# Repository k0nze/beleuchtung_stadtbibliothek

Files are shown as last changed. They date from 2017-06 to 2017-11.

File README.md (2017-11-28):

# Beleuchtung der LEGO Stadtbibliothek Stuttgart

## Platine
KiCad Projekt:
[beleuchtung_stadtbibliothek.pro](./kicad/beleuchtung_stadtbibliothek.pro)

Pin-Belegung `CON1`:

 * 1 => `VCC`
 * 2 => `GND`
 * 3 => `CLK`
 * 4 => Clear für für Schieberegister
 * 5 => Data-Input für Schieberegister 
 * 6 => Enable für LED-Treiber 

### Schaltplan
[beleuchtung_stadtbibliothek.sch](./kicad/beleuchtung_stadtbibliothek.sch)

### Layout/PCB
[beleuchtung_stadtbibliothek.kicad_pcb](./kicad/beleuchtung_stadtbibliothek.kicad_pcb)

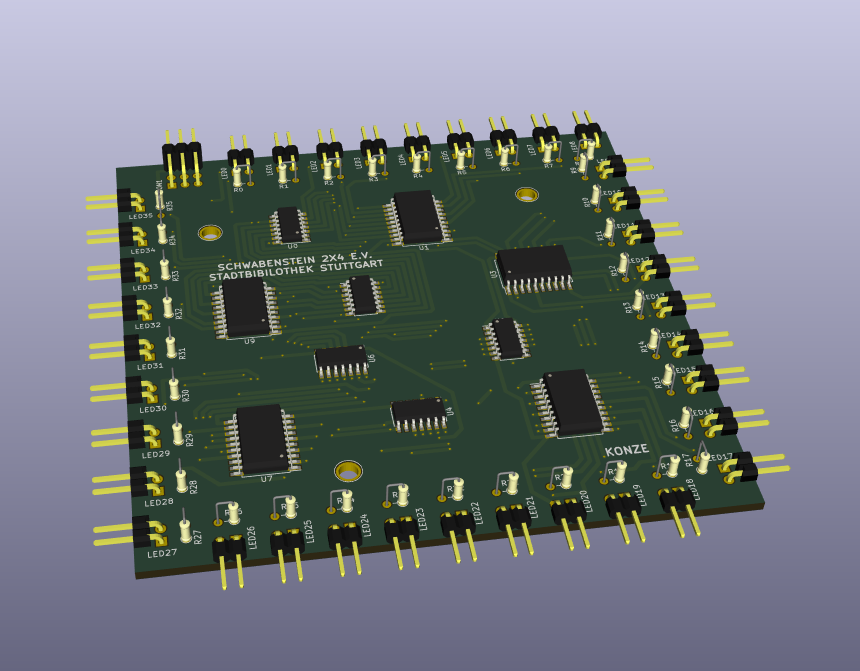
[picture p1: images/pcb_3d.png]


### Gerber Dateien für Seeedstudio
[kicad/gerber](./kicad/gerber)

### Bauelemente (für 10 Platinen)
Reichelt:

 * 10x [Stiftleisten 2,54 mm, 2X03, gewinkelt](https://www.reichelt.de/Stiftleisten/MPE-088-2-006/3/index.html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)
 * 15x [50pol. Stiftleiste, gewinkelt, RM 2,54](https://www.reichelt.de/Stiftleisten/SL-1X50W-2-54/3/index.html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)
 * 50x [SMD HC 164](https://www.reichelt.de/ICs-74HC-SMD/SMD-HC-164/3/index.html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)
 * 50x [SMD HC 244](https://www.reichelt.de/ICs-74HC-SMD/SMD-HC-244/3/index.html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)
 * 2x [CR 44](https://www.reichelt.de/Flussmittel-Loetpasten/CR-44/3/index.html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)
 * (3-5)x [GS25E05-P1J](https://www.reichelt.de/Festspannungsnetzteile/GS25E05-P1J/3/index.html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)
 * (3-5)x [DELOCK 65524](https://www.reichelt.de/Hohlstecker/DELOCK-65524/3/index.html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)
 * 1x [EL 6-FACH MS-LG](https://www.reichelt.de/Steckdosenleiste-allgemein/EL-6-FACH-MS-LG/3/index.html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)
 * 360x [1/4W 5%](https://www.reichelt.de/1-4W-5-/2/index.html?ACTION=2&LA=2&GROUPID=3061)

eBay:

 * 500x [3mm LED weiß](http://www.ebay.de/itm/Transparente-High-Quality-LEDs-Leucht-Dioden-in-verschiedenen-Grosen-und-Farben-/171370401875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)
 * 18x [20cm Dupont Draht 40x](http://www.ebay.de/itm/40x-Dupont-Draht-Rainbow-Color-Jumper-Kabel-Buchse-Buchse-20cm-/351673233241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)

Bricklink:

 * 360x [4070, white](https://www.bricklink.com/v2/catalog/catalogitem.page?P=4070#T=S&C=1&O={"color":1})

## Steuerung
Die Steuerung wird derzeit durch einen Arduino Mega 2560 übernommen. Der Anschluss der Steuerleitungen für die Platinen ist in [demo0.ino](./src/demo0/demo0.ino) dokumentiert. In [demo0.ino](./src/demo0/demo0.ino) werden alle LEDs eingeschaltet.

### Verdrahtung

* `VCC`: orange
* `GND`: blau/schwarz
* `CLK`: violett/orange
* reset: weiß
* data: gelb/grün
* driver: grau/braun

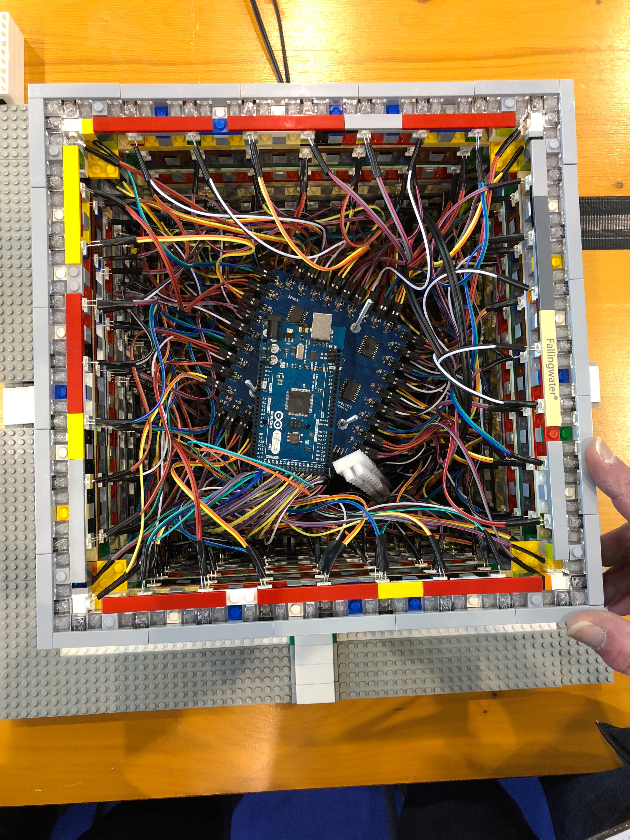
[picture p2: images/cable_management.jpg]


### Fertiges Modell
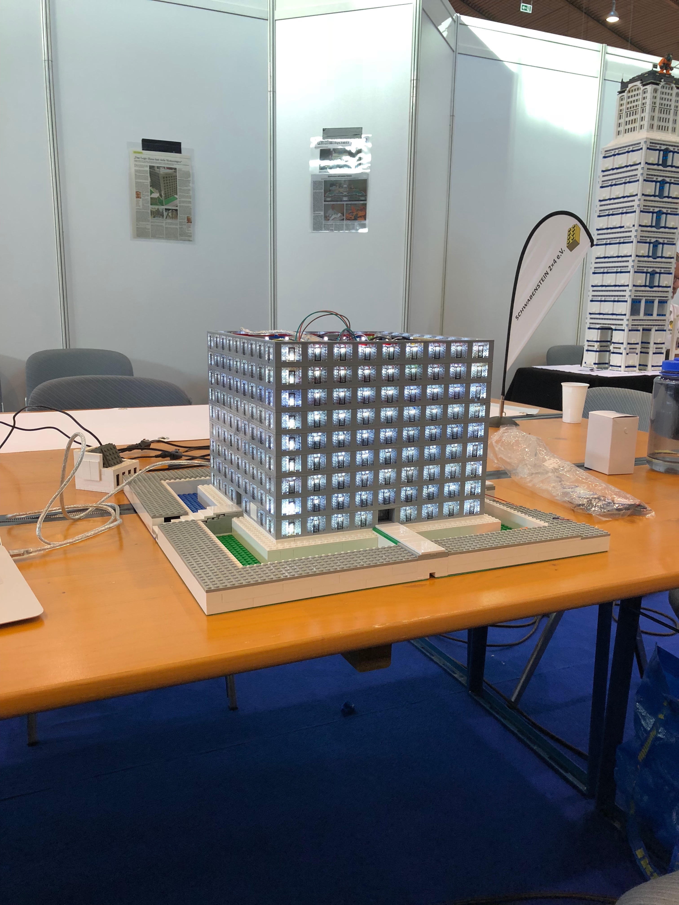
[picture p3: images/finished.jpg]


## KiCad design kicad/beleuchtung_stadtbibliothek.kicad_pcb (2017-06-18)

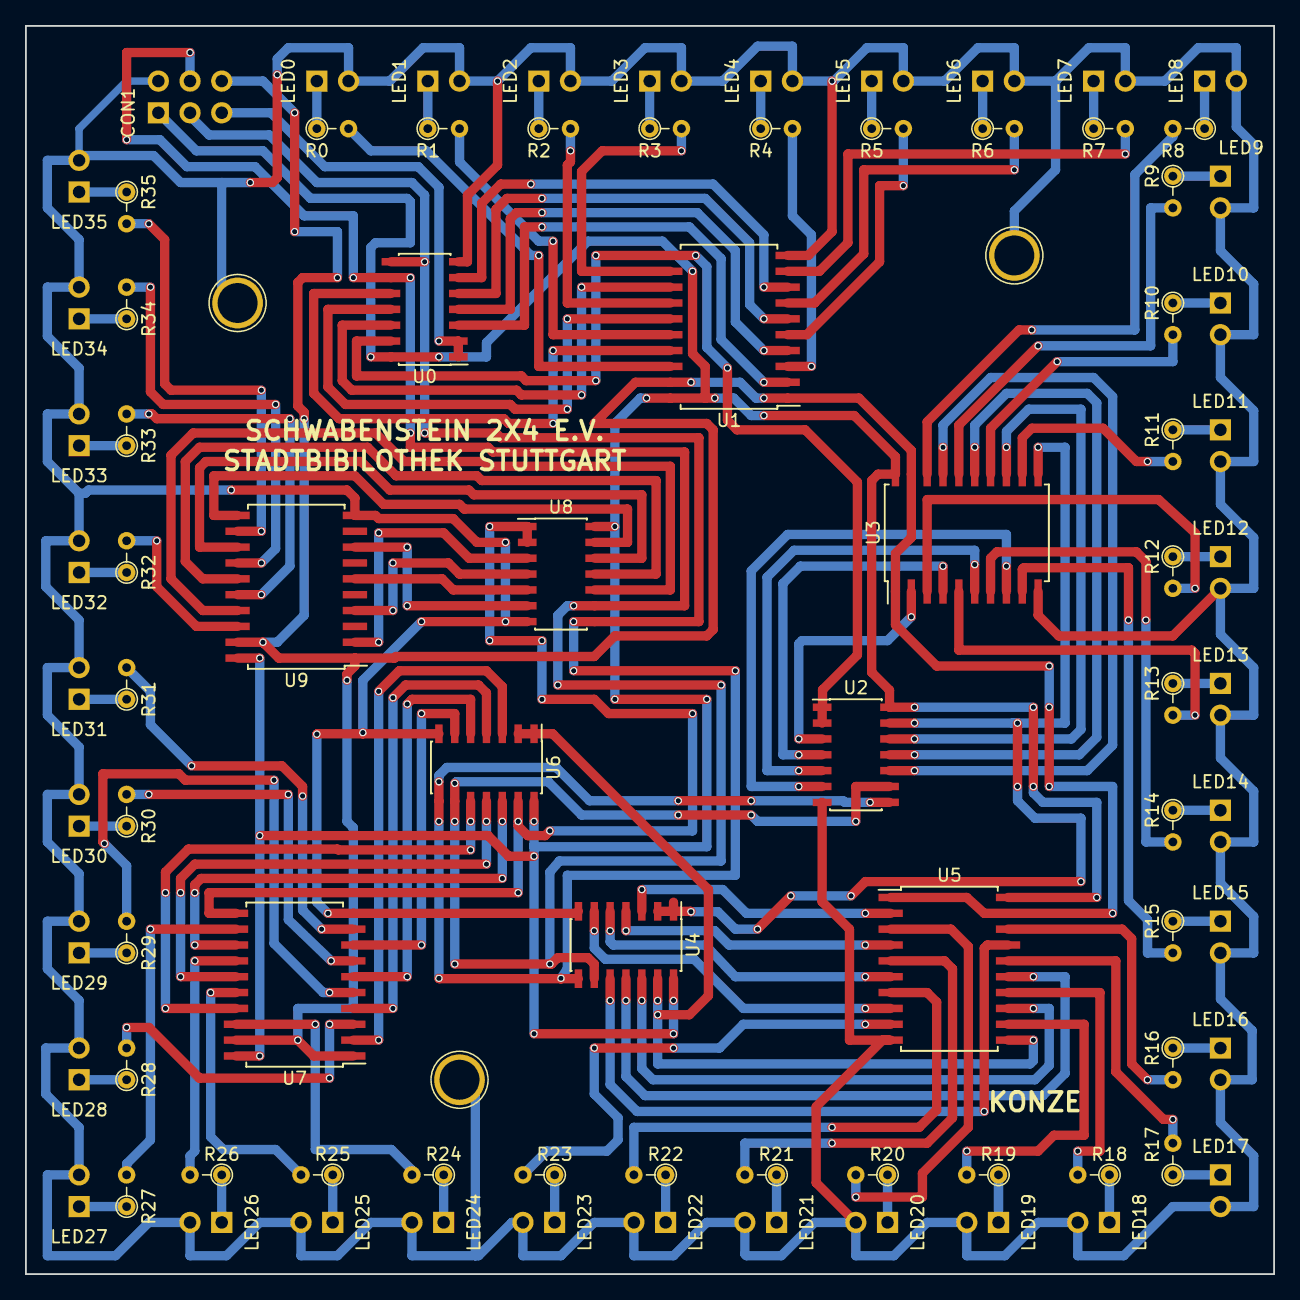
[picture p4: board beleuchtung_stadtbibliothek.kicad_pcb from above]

Board: 2 copper layers, 100.0 x 100.0 mm, 83 parts (0 on the bottom side), 118 nets.

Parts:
CON1: CONN_02X03; Pin_Header_Angled_2x03_Pitch2.54mm
LED0, LED1, LED2, LED3, LED4, LED5, LED6, LED7, LED8, LED9, LED10, LED11, LED12, LED13, LED14, LED15, LED16, LED17, LED18, LED19, LED20, LED21, LED22, LED23, LED24, LED25, LED26, LED27, LED28, LED29, LED30, LED31, LED32, LED33, LED34, LED35: CONN_02X01; Pin_Header_Angled_1x02_Pitch2.54mm
R0, R1, R2, R3, R4, R5, R6, R7, R8, R9, R10, R11, R12, R13, R14, R15, R16, R17, R18, R19, R20, R21, R22, R23, R24, R25, R26, R27, R28, R29, R30, R31, R32, R33, R34, R35: 75; R_Axial_DIN0204_L3.6mm_D1.6mm_P2.54mm_Vertical
U0, U2, U4, U6, U8: 74HC164; SOIC-14_3.9x8.7mm_Pitch1.27mm
U1, U3, U5, U7, U9: 74HC244; SOIC-20W_7.5x12.8mm_Pitch1.27mm

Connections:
Earth: CON1.2, LED0.2, LED1.2, LED2.2, LED3.2, LED4.2, LED5.2, LED6.2, LED7.2, LED8.2, LED9.2, LED10.2, LED11.2, LED12.2, LED13.2, LED14.2, LED15.2, LED16.2, LED17.2, LED18.2, LED19.2, LED20.2, LED21.2, LED22.2, LED23.2, LED24.2, LED25.2, LED26.2, LED27.2, LED28.2, LED29.2, LED30.2, LED31.2, LED32.2, LED33.2, LED34.2, LED35.2, U0.7, U1.10, U2.7, U3.10, U4.7, U5.10, U6.7, U7.10, U8.7, U9.10
unnamed: CON1.3, U0.8, U2.8, U4.8, U6.8, U8.8
unnamed: CON1.4, U0.9, U2.9, U4.9, U6.9, U8.9
unnamed: CON1.5, U0.1, U0.2
unnamed: CON1.6, U1.1, U1.19, U3.1, U3.19, U5.1, U5.19, U7.1, U7.19, U9.1, U9.19
unnamed: LED0.1, R0.1
unnamed: LED1.1, R1.1
unnamed: LED2.1, R2.1
unnamed: LED3.1, R3.1
unnamed: LED4.1, R4.1
unnamed: LED5.1, R5.1
unnamed: LED6.1, R6.1
unnamed: LED7.1, R7.1
unnamed: LED8.1, R8.1
unnamed: LED9.1, R9.1
unnamed: LED10.1, R10.1
unnamed: LED11.1, R11.1
unnamed: LED12.1, R12.1
unnamed: LED13.1, R13.1
unnamed: LED14.1, R14.1
unnamed: LED15.1, R15.1
unnamed: LED16.1, R16.1
unnamed: LED17.1, R17.1
unnamed: LED18.1, R18.1
unnamed: LED19.1, R19.1
unnamed: LED20.1, R20.1
unnamed: LED21.1, R21.1
unnamed: LED22.1, R22.1
unnamed: LED23.1, R23.1
unnamed: LED24.1, R24.1
unnamed: LED25.1, R25.1
unnamed: LED26.1, R26.1
unnamed: LED27.1, R27.1
unnamed: LED28.1, R28.1
unnamed: LED29.1, R29.1
unnamed: LED30.1, R30.1
unnamed: LED31.1, R31.1
unnamed: LED32.1, R32.1
unnamed: LED33.1, R33.1
unnamed: LED34.1, R34.1
unnamed: LED35.1, R35.1
unnamed: R0.2, U1.18
unnamed: R1.2, U1.16
unnamed: R2.2, U1.14
unnamed: R3.2, U1.12
unnamed: R4.2, U1.3
unnamed: R5.2, U1.5
unnamed: R6.2, U1.7
unnamed: R7.2, U1.9
unnamed: R8.2, U3.18
unnamed: R9.2, U3.16
unnamed: R10.2, U3.14
unnamed: R11.2, U3.12
unnamed: R12.2, U3.3
unnamed: R13.2, U3.5
unnamed: R14.2, U3.7
unnamed: R15.2, U3.9
unnamed: R16.2, U5.18
unnamed: R17.2, U5.16
unnamed: R18.2, U5.14
unnamed: R19.2, U5.12
unnamed: R20.2, U5.3
unnamed: R21.2, U5.5
unnamed: R22.2, U5.7
unnamed: R23.2, U5.9
unnamed: R24.2, U7.18
unnamed: R25.2, U7.16
unnamed: R26.2, U7.14
unnamed: R27.2, U7.12
unnamed: R28.2, U7.3
unnamed: R29.2, U7.5
unnamed: R30.2, U7.7
unnamed: R31.2, U7.9
unnamed: R32.2, U9.18
unnamed: R33.2, U9.16
unnamed: R34.2, U9.14
unnamed: R35.2, U9.12
unnamed: U0.3, U1.2
unnamed: U0.4, U1.4
unnamed: U0.5, U1.6
unnamed: U0.6, U1.8
unnamed: U0.10, U1.17
unnamed: U0.11, U1.15
unnamed: U0.12, U1.13
unnamed: U0.13, U1.11, U2.1, U2.2
unnamed: U2.3, U3.2
unnamed: U2.4, U3.4
unnamed: U2.5, U3.6
unnamed: U2.6, U3.8
unnamed: U2.10, U3.17
unnamed: U2.11, U3.15
unnamed: U2.12, U3.13
unnamed: U2.13, U3.11, U4.1, U4.2
unnamed: U4.3, U5.2
unnamed: U4.4, U5.4
unnamed: U4.5, U5.6
unnamed: U4.6, U5.8
unnamed: U4.10, U5.17
unnamed: U4.11, U5.15
unnamed: U4.12, U5.13
unnamed: U4.13, U5.11, U6.1, U6.2
unnamed: U6.3, U7.2
unnamed: U6.4, U7.4
unnamed: U6.5, U7.6
unnamed: U6.6, U7.8
unnamed: U6.10, U7.17
unnamed: U6.11, U7.15
unnamed: U6.12, U7.13
unnamed: U6.13, U7.11, U8.1, U8.2
unnamed: U8.3, U9.2
unnamed: U8.4, U9.4
unnamed: U8.5, U9.6
unnamed: U8.6, U9.8
unnamed: U8.10, U9.17
unnamed: U8.11, U9.15
unnamed: U8.12, U9.13
unnamed: U8.13, U9.11
VCC: CON1.1, U0.14, U1.20, U2.14, U3.20, U4.14, U5.20, U6.14, U7.20, U8.14, U9.20

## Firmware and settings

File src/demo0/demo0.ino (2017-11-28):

// Pin numbers
int reset = 23;

// floor         0   1   2   3   4   5   6  7  8
int clock [9] = {22, 26, 30, 34, 38, 42, 4, 1, 7};
int data [9] =  {24, 28, 32, 36, 40, 44, 3, 0, 6};
int driver[9] = {25, 29, 33, 37, 41, 45, 5, 2, 8};

byte all_on[] {0xff, 0xff, 0xff, 0xff, 0xff};

void setup() {
  for(int i = 0; i < 9; i++) {
    pinMode(data[i], OUTPUT);
    pinMode(clock[i], OUTPUT);
    pinMode(driver[i], OUTPUT);
    digitalWrite(driver[i],LOW);
  }
  
  pinMode(reset,OUTPUT);
  digitalWrite(reset,LOW);
  delay(100);
  digitalWrite(reset,HIGH);
  
}

void loop() {

  // turn all LEDs on
  for (int i = 0; i < 5; i++) {
      for(int j = 0; j < 9; j++) {
        shiftOut(data[j], clock[j], MSBFIRST, all_on[i]);
      }
  }

  delay(1000);

/*
  // turn on each single LED 
  for(int j = 0; j < 36; j++) {
    for(int i = 0; i < 5; i++) {
      
      digitalWrite(driver,HIGH);
      delay(2);
      shiftOut(data, clock, MSBFIRST, single_on[j][i]);
      delay(2);
      digitalWrite(driver,LOW);
      
    }
    delay(1000);
  }
  */
  
  delay(1000);
}

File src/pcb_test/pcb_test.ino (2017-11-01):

// Pin numbers
int clock = 22;
int reset = 23;
int data = 24;
int driver = 25;

byte all_on[] {0xff, 0xff, 0xff, 0xff, 0xff};

byte single_on[][5] {
  {0x0, 0x00, 0x00, 0x00, 0x01}, // 0
  {0x0, 0x00, 0x00, 0x00, 0x02}, // 1
  {0x0, 0x00, 0x00, 0x00, 0x04}, // 2
  {0x0, 0x00, 0x00, 0x00, 0x08}, // 3
  {0x0, 0x00, 0x00, 0x00, 0x10}, // 4
  {0x0, 0x00, 0x00, 0x00, 0x20}, // 5
  {0x0, 0x00, 0x00, 0x00, 0x40}, // 6
  {0x0, 0x00, 0x00, 0x00, 0x80}, // 7

  {0x0, 0x00, 0x00, 0x01, 0x00}, // 8
  {0x0, 0x00, 0x00, 0x02, 0x00}, // 9
  {0x0, 0x00, 0x00, 0x04, 0x00}, // 10
  {0x0, 0x00, 0x00, 0x08, 0x00}, // 11
  {0x0, 0x00, 0x00, 0x10, 0x00}, // 12
  {0x0, 0x00, 0x00, 0x20, 0x00}, // 13
  {0x0, 0x00, 0x00, 0x40, 0x00}, // 14
  {0x0, 0x00, 0x00, 0x80, 0x00}, // 15

  {0x0, 0x00, 0x01, 0x00, 0x00}, // 16
  {0x0, 0x00, 0x02, 0x00, 0x00}, // 17
  {0x0, 0x00, 0x04, 0x00, 0x00}, // 18
  {0x0, 0x00, 0x08, 0x00, 0x00}, // 19
  {0x0, 0x00, 0x10, 0x00, 0x00}, // 20
  {0x0, 0x00, 0x20, 0x00, 0x00}, // 21
  {0x0, 0x00, 0x40, 0x00, 0x00}, // 22
  {0x0, 0x00, 0x80, 0x00, 0x00}, // 23

  {0x0, 0x01, 0x00, 0x00, 0x00}, // 24
  {0x0, 0x02, 0x00, 0x00, 0x00}, // 25
  {0x0, 0x04, 0x00, 0x00, 0x00}, // 26
  {0x0, 0x08, 0x00, 0x00, 0x00}, // 27
  {0x0, 0x10, 0x00, 0x00, 0x00}, // 28
  {0x0, 0x20, 0x00, 0x00, 0x00}, // 29
  {0x0, 0x40, 0x00, 0x00, 0x00}, // 30
  {0x0, 0x80, 0x00, 0x00, 0x00}, // 31

  {0x1, 0x00, 0x00, 0x00, 0x00}, // 32
  {0x2, 0x00, 0x00, 0x00, 0x00}, // 33
  {0x4, 0x00, 0x00, 0x00, 0x00}, // 34
  {0x8, 0x00, 0x00, 0x00, 0x00}, // 35
};

void setup() {
  pinMode(data,OUTPUT);
  pinMode(clock,OUTPUT);
  pinMode(reset,OUTPUT);
  pinMode(driver,OUTPUT);
  digitalWrite(reset,LOW);
  delay(100);
  digitalWrite(reset,HIGH);
  digitalWrite(driver,LOW);
}

void loop() {

  // turn all LEDs on
  for (int i = 0; i < 5; i++) {
      shiftOut(data, clock, MSBFIRST, all_on[i]);
  }

  delay(1000);

  // turn on each single LED 
  for(int j = 0; j < 36; j++) {
    for(int i = 0; i < 5; i++) {
      
      digitalWrite(driver,HIGH);
      delay(2);
      shiftOut(data, clock, MSBFIRST, single_on[j][i]);
      delay(2);
      digitalWrite(driver,LOW);
      
    }
    delay(1000);
  }
  
  delay(1000);
}

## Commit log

2017-06-18 KiCad Dateien hinzugefügt.
    [belechtung_stadtbibliothek.kicad_pcb, belechtung_stadtbibliothek.sch]
2017-06-18 Dateien umbenannt.
    [beleuchtung_stadtbibliothek.kicad_pcb, beleuchtung_stadtbibliothek.sch]
2017-06-18 Dateien organisiert.
    [beleuchtung_stadtbibliothek.kicad_pcb, beleuchtung_stadtbibliothek.sch]
2017-06-18 Materialliste eingetragen.
2017-06-23 Gerber Dateien für Seeedstudio hinzugefügt und Skript zum setzten der Dateinamen und packen als zip.
    [beleuchtung_stadtbibliothek-B.Cu.gbl, beleuchtung_stadtbibliothek-B.Mask.gbs, beleuchtung_stadtbibliothek-B.SilkS.gbo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]
2017-11-01 Programm zum Testen der Platinen hinzugefügt.
2017-11-28 Verdrahtung und Demoprogramm hinzugefügt.
